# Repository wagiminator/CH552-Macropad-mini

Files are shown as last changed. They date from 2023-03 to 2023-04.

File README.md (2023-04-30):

# CH552E MacroPad mini
The MacroPad mini is a highly versatile keyboard extension that boasts three programmable keys. These keys can be configured to execute a vast array of actions, including the triggering of specific key combinations and sequences. Additionally, the firmware used to operate the MacroPad can be easily modified to suit the needs of the user.

Each button on the MacroPad is also equipped with an addressable LED (NeoPixel), which can be programmed in the same way as the keys. This provides the user with an additional level of customization, allowing them to assign specific colors or patterns to each key, making them easier to identify at a glance.

Connecting the MacroPad to a PC is a breeze, as it simply plugs in via USB. Once connected, the MacroPad is immediately recognized by the PC as an HID multimedia keyboard, meaning that it requires no special drivers to function. This makes the MacroPad an incredibly user-friendly and accessible option for those looking to expand their keyboard capabilities.

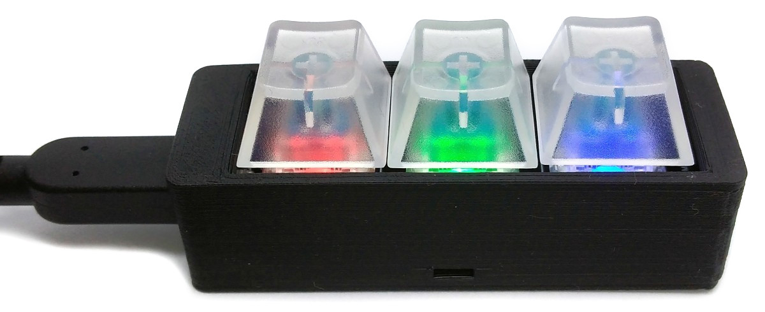
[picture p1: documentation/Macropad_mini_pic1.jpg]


# Hardware
## Schematic
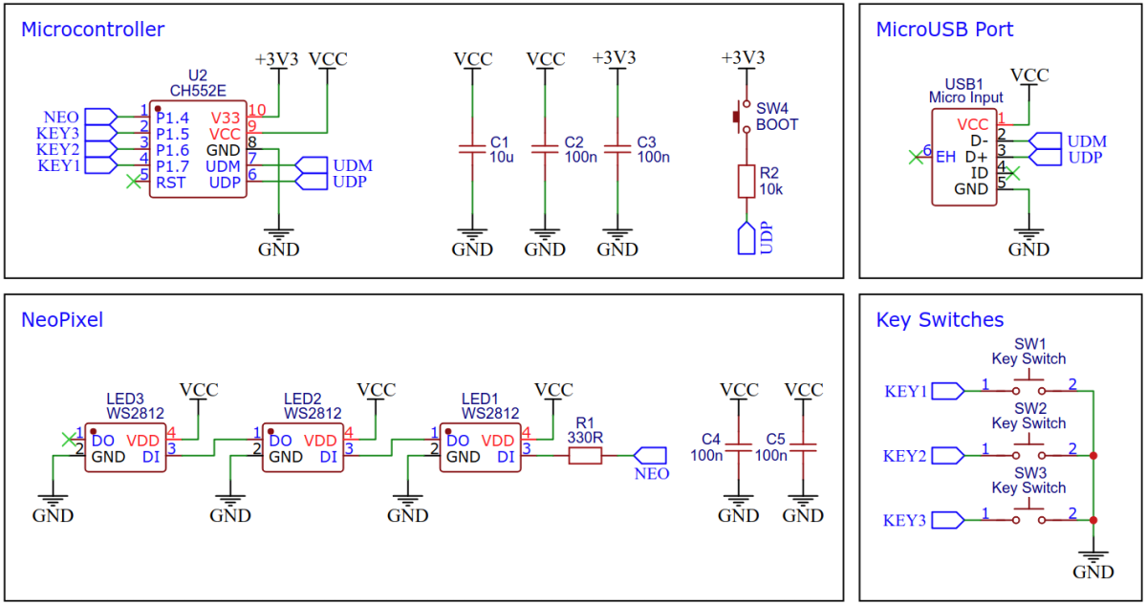
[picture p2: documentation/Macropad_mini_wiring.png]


## CH552E 8-bit USB Device Microcontroller
The CH552E is a low-cost, enhanced E8051 core microcontroller compatible with the MCS51 instruction set. It has an integrated USB 2.0 controller with full-speed data transfer (12 Mbit/s) and supports up to 64 byte data packets with integrated FIFO and direct memory access (DMA). The CH552E has a factory built-in bootloader so firmware can be uploaded directly via USB without the need for an additional programming device.

## Buildung Instructions
1. Take the Gerber files and send them to a PCB manufacturer of your choosing. They will use these files to create the circuit board for your device.
2. Once you have the PCB, you can start soldering the components onto it. Use the BOM (bill of materials) and schematic as a guide to make sure everything is connected correctly.
3. Upload the firmware by following the instructions in the next section (see below).
4. To create the case for your device, use the STL files with your 3D printer. Make sure to use transparent filament for the keycaps.
5. After printing, secure the PCB to the bottom of the case using four self-tapping M2x5mm screws.
6. Finally, assemble the case. Place the keycaps onto the switches. Your device is now ready to use!

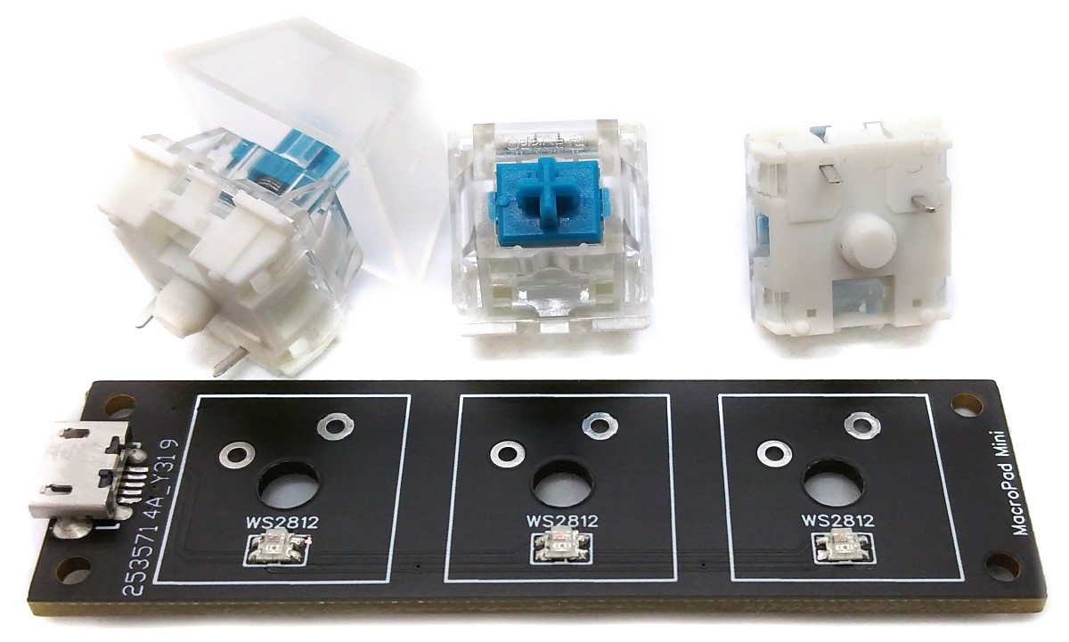
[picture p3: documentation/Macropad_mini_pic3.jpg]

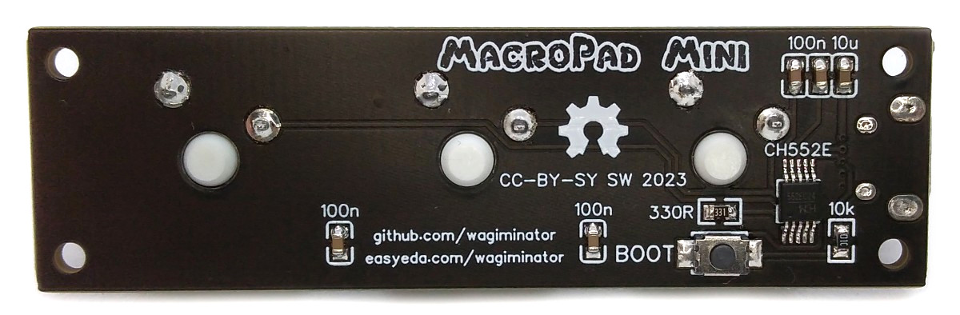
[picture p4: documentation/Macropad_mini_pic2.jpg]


# Modifying, Compiling and Installing Firmware
## Customizing the Firmware
The definition of the macros and their assignment to individual key events is done by adjusting the firmware accordingly, which allows maximum freedom and flexibility. To do this, open the macropad_mini.c file and edit the section with the macro functions. The source code is commented in such a way that it should be possible to make adjustments even with basic programming skills.

## Preparing the CH55x Bootloader
### Installing Drivers for the CH55x Bootloader
On Linux you do not need to install a driver. However, by default Linux will not expose enough permission to upload your code with the USB bootloader. In order to fix this, open a terminal and run the following commands:

```
echo 'SUBSYSTEM=="usb", ATTR{idVendor}=="4348", ATTR{idProduct}=="55e0", MODE="666"' | sudo tee /etc/udev/rules.d/99-ch55x.rules
sudo service udev restart
```

For Windows, you need the [CH372 driver](http://www.wch-ic.com/downloads/CH372DRV_EXE.html). Alternatively, you can also use the [Zadig Tool](https://zadig.akeo.ie/) to install the correct driver. Here, click "Options" and "List All Devices" to select the USB module, and then install the libusb-win32 driver. To do this, the board must be connected and the CH55x must be in bootloader mode.

### Entering CH55x Bootloader Mode
A brand new chip starts automatically in bootloader mode as soon as it is connected to the PC via USB. Once firmware has been uploaded, the bootloader must be started manually for new uploads. To do this, the board must first be disconnected from the USB port and all voltage sources. Now press the BOOT button and keep it pressed while reconnecting the board to the USB port of your PC. The chip now starts again in bootloader mode, the BOOT button can be released and new firmware can be uploaded within the next couple of seconds.

Once the MacroPad firmware is installed, the bootloader can also be entered by holding down key 1 while connecting the device to the USB port. In this way, the case does not have to be opened when new firmware is to be installed. All NeoPixels will then light up white as long as the device is in bootloader mode (approx. 10 seconds).

## Compiling and Uploading using the makefile
### Installing SDCC Toolchain for CH55x
Install the [SDCC Compiler](https://sdcc.sourceforge.net/). In order for the programming tool to work, Python3 must be installed on your system. To do this, follow these [instructions](https://www.pythontutorial.net/getting-started/install-python/). In addition [pyusb](https://github.com/pyusb/pyusb) must be installed. On Linux (Debian-based), all of this can be done with the following commands:

```
sudo apt install build-essential sdcc python3 python3-pip
sudo pip install pyusb
```

### Compiling and Uploading Firmware
- Open a terminal.
- Navigate to the folder with the makefile. 
- Connect the board and make sure the CH55x is in bootloader mode. 
- Run ```make flash``` to compile and upload the firmware. 
- If you don't want to compile the firmware yourself, you can also upload the precompiled binary. To do this, just run ```python3 ./tools/chprog.py macropad_mini.bin```.

## Compiling and Uploading using the Arduino IDE
### Installing the Arduino IDE and CH55xduino
Install the [Arduino IDE](https://www.arduino.cc/en/software) if you haven't already. Install the [CH55xduino](https://github.com/DeqingSun/ch55xduino) package by following the instructions on the website.

### Compiling and Uploading Firmware
- Copy the .ino and .c files as well as the /src folder together into one folder and name it like the .ino file. 
- Open the .ino file in the Arduino IDE.
- Go to **Tools -> Board -> CH55x Boards** and select **CH552 Board**.
- Go to **Tools** and choose the following board options:
  - **Clock Source:**   16 MHz (internal)
  - **Upload Method:**  USB
  - **USB Settings:**   USER CODE /w 266B USB RAM
- Connect the board and make sure the CH55x is in bootloader mode. 
- Click **Upload**.

# References, Links and Notes
1. [EasyEDA Design Files](https://oshwlab.com/wagiminator)
2. [CH551/552 Datasheet](http://www.wch-ic.com/downloads/CH552DS1_PDF.html)
3. [SDCC Compiler](https://sdcc.sourceforge.net/)
4. [CH552G MacroPad plus](https://github.com/wagiminator/CH552-MacroPad-plus)
5. [CH552E USB Knob](https://github.com/wagiminator/CH552-USB-Knob)

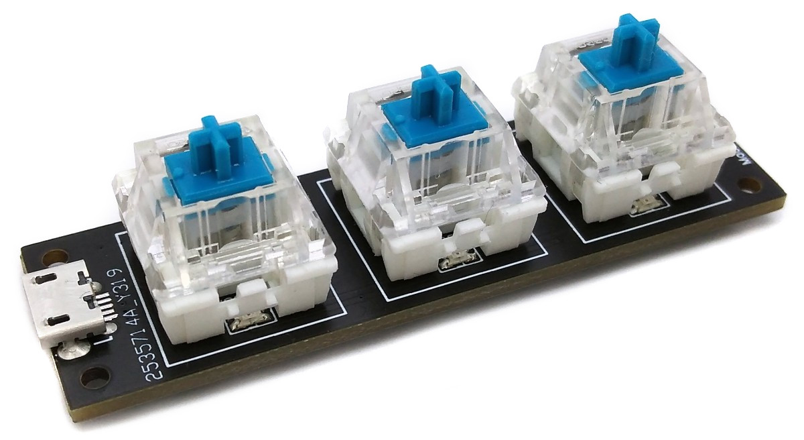
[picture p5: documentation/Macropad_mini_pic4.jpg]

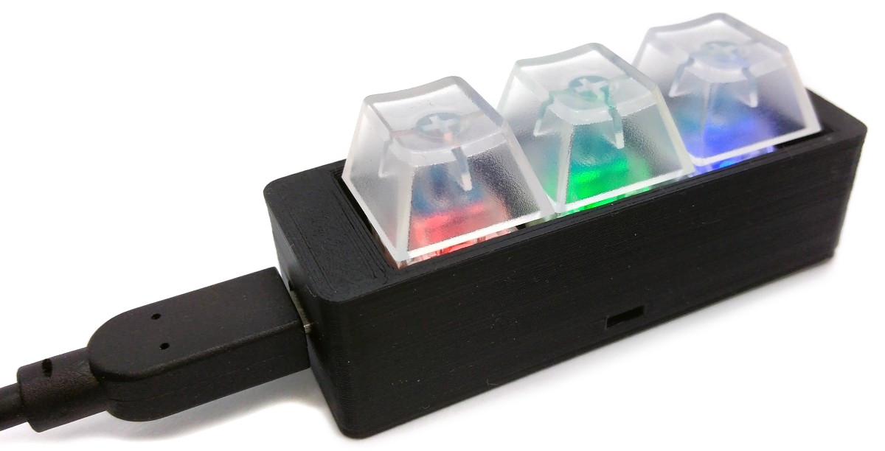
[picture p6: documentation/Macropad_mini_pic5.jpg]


# License


This work is licensed under Creative Commons Attribution-ShareAlike 3.0 Unported License. 
(http://creativecommons.org/licenses/by-sa/3.0/)

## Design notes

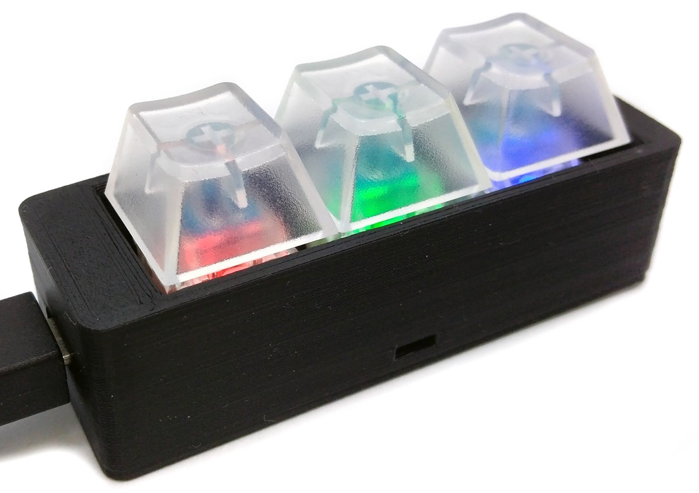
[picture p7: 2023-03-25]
documentation/Macropad_mini_pic6.jpg

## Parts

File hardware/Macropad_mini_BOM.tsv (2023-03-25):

ID | Name | Designator | Footprint | Quantity | Manufacturer Part | Manufacturer | Supplier | Supplier Part
1 | 10u | C1 | C_0603 | 1 | CL10A106KP8NNNC | SAMSUNG | LCSC | C19702
2 | 100n | C2,C3,C4,C5 | C_0603 | 4 | CC0603KRX7R9BB104 | YAGEO | LCSC | C14663
3 | WS2812 | LED1,LED2,LED3 | WS2812-2020 | 3 | WS2812C-2020-V1 | worldsemi | LCSC | C2976072
4 | 330R | R1 | 0603 | 1 | 0603WAF3300T5E | UniOhm | LCSC | C23138
5 | 10k | R2 | 0603 | 1 | 0603WAF1002T5E | UniOhm | LCSC | C25804
6 | Key Switch | SW1,SW2,SW3 | KEY-TH | 3 | CPG151101D213 | Kailh(凯华) | LCSC | C400235
7 | BOOT | SW4 | SW-SMD_L4.0-W2.9-LS5.0 | 1 | TS-1185-C-A-B-B | XKB Enterprise | LCSC | C465999
8 | CH552E | U2 | MSOP-10 | 1 | CH552E | WCH(Jiangsu Qin Heng) | LCSC | C967938
9 | Micro Input | USB1 | MINI-USB-SMD_U254-051T-4BH23-S2B | 1 | U254-051T-4BH23-S2B | XKB Enterprise | LCSC | C319164

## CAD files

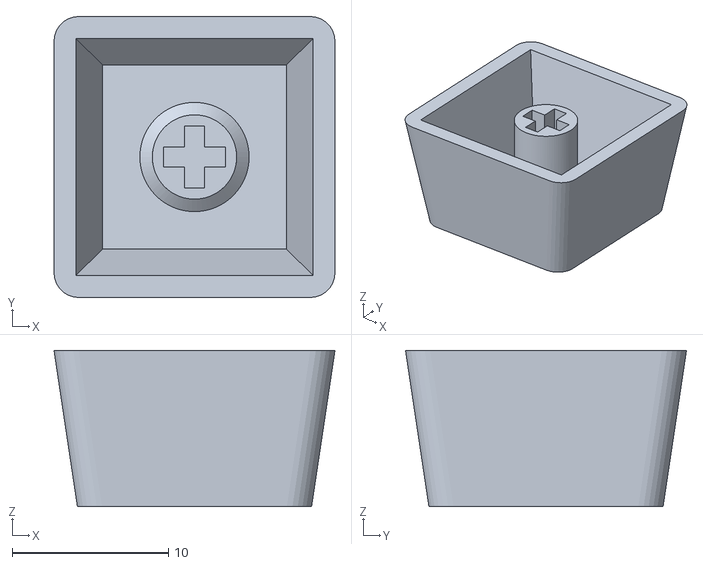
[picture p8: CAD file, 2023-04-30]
3dprint/Macropad_mini_keycap.stl
18.0 x 18.0 x 10.0

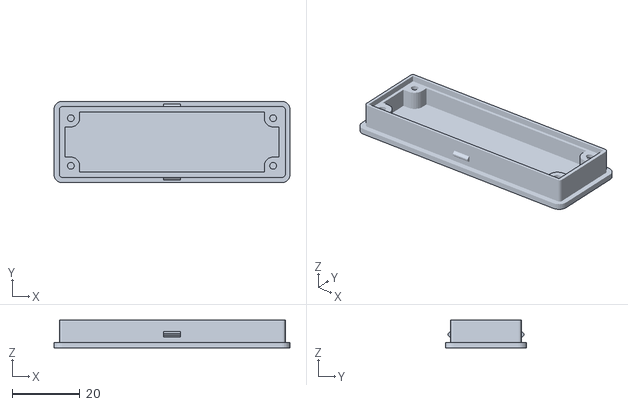
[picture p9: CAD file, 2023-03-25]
3dprint/Macropad_mini_case_bottom.stl
69.8 x 24.1 x 8.20

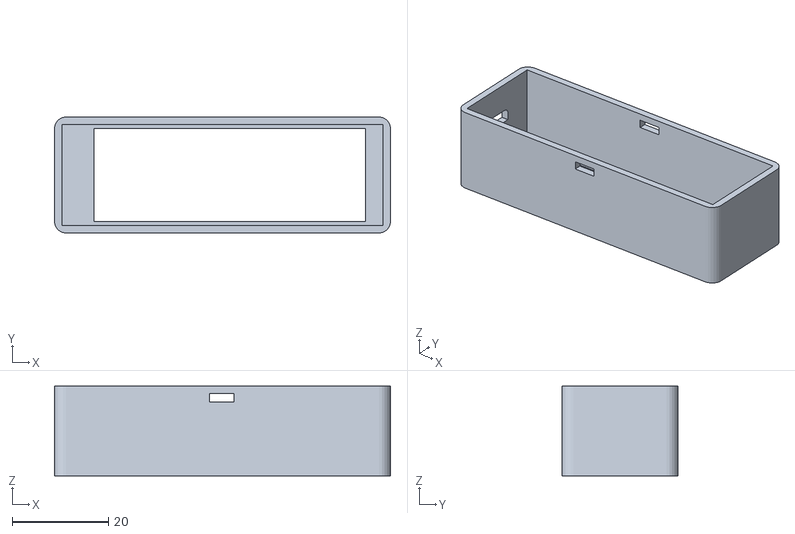
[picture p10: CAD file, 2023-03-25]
3dprint/Macropad_mini_case_top.stl
69.8 x 24.1 x 18.6

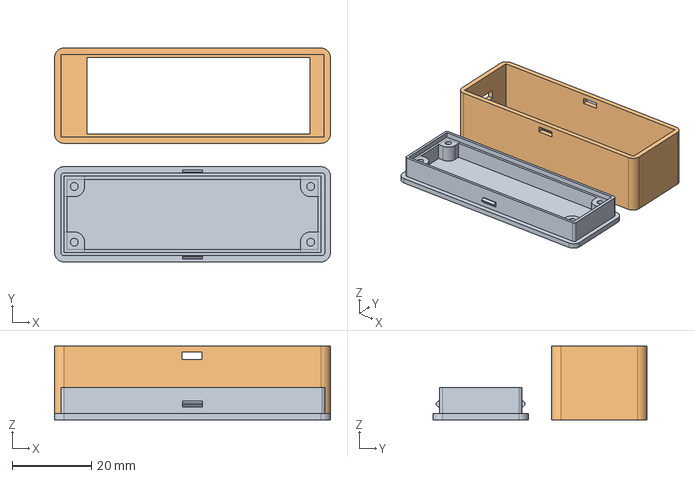
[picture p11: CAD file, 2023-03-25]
3dprint/Macropad_mini_case.fcstd
69.8 x 54.1 x 18.6 mm
Bottom
Top

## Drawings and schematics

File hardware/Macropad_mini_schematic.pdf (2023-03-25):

## MicroUSB Port

## Microcontroller

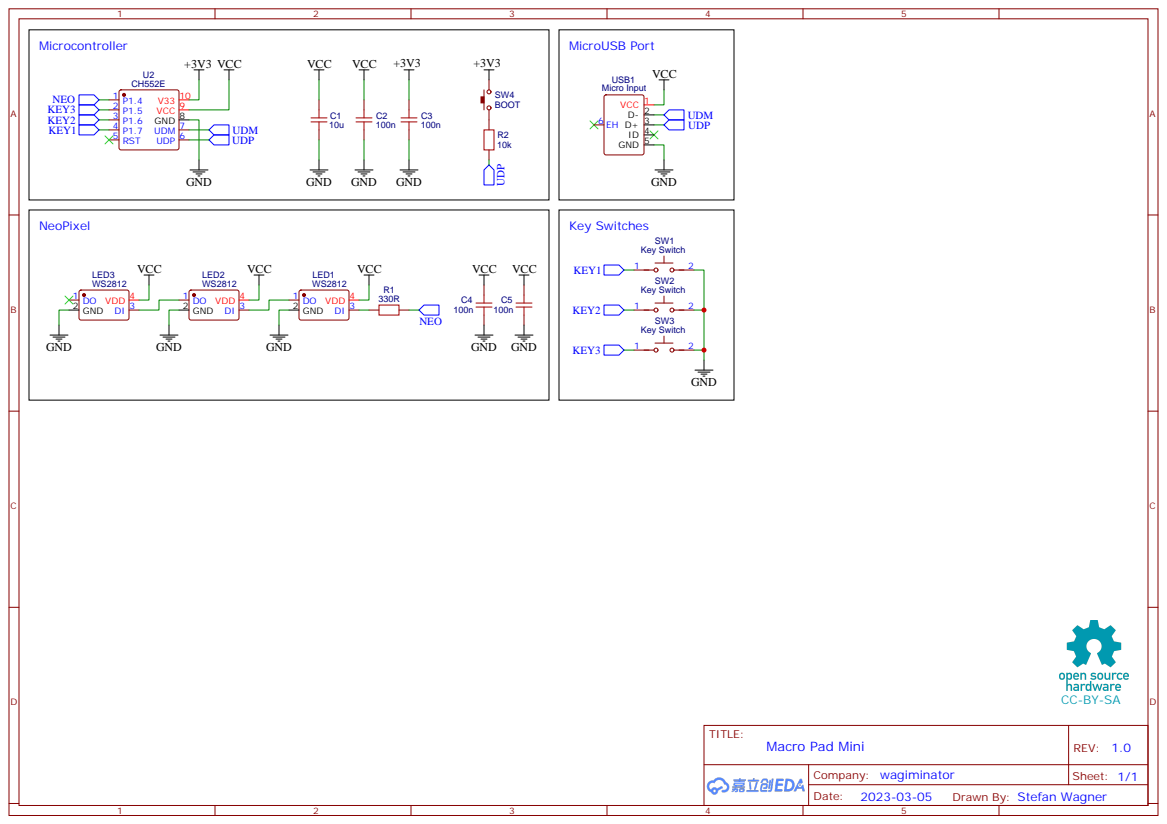
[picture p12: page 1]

Drawn By: Stefan Wagner

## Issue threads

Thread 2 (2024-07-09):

Can't create bin file with arduino

ArthusPVP, 2024-07-09:
Hi, I want to create a bin file to upload to the ch552 but It doesn't works. Can you please give me the versions of the libraries you used for this project 😥? thx

wagiminator, 2024-07-11:
You don't need external libraries, just make sure that the "src" folder is included.

ArthusPVP, 2024-07-11:
Yes, I am able to create the .bin file it it doesn’t work on the macro pad and does some weird things ArthusLe 11 juil. 2024 à 09:03, Stefan Wagner ***@***.***> a écrit :
You don't need external libraries, just make sure that the "src" folder is included.

—Reply to this email directly, view it on GitHub, or unsubscribe.You are receiving this because you authored the thread.Message ID: ***@***.***>

wagiminator, 2024-07-11:
Ah, OK. Did you compile with ArduinoIDE or with the makefile?

ArthusPVP, 2024-07-11:
I compiled with Arduino IDEArthusLe 11 juil. 2024 à 09:34, Stefan Wagner ***@***.***> a écrit :
Ah, OK. Did you compile with ArduinoIDE or with the makefile?

—Reply to this email directly, view it on GitHub, or unsubscribe.You are receiving this because you authored the thread.Message ID: ***@***.***>

wagiminator, 2024-07-11:
Make sure you have the correct settings especially for USB. However, I can't guarantee that this will work with every Arduino version and every version of CH55xduino. The safest way is to compile with make.

ArthusPVP, 2024-07-22:
thx

Closed 2024-07-22.

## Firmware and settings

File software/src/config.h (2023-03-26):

// ===================================================================================
// User Configurations for CH552E USB MacroPad Mini
// ===================================================================================

#pragma once

// Pin definitions
#define PIN_NEO             P14         // pin connected to NeoPixel
#define PIN_KEY3            P15         // pin connected to key 3
#define PIN_KEY2            P16         // pin connected to key 2
#define PIN_KEY1            P17         // pin connected to key 1

// NeoPixel configuration
#define NEO_GRB                         // type of pixel: NEO_GRB or NEO_RGB

// USB device descriptor
#define USB_VENDOR_ID       0x1189      // VID
#define USB_PRODUCT_ID      0x8890      // PID
#define USB_DEVICE_VERSION  0x0100      // v1.0 (BCD-format)

// USB configuration descriptor
#define USB_MAX_POWER_mA    50          // max power in mA 

// USB descriptor strings
#define MANUFACTURER_STR    'w','a','g','i','m','i','n','a','t','o','r'
#define PRODUCT_STR         'M','a','c','r','o','P','a','d'
#define SERIAL_STR          'C','H','5','5','2','x','H','I','D'
#define INTERFACE_STR       'H','I','D','-','K','e','y','b','o','a','r','d'

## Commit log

2023-04-02 Added support for Arduino IDE
2023-04-30 Editorial changes
    [Macropad_mini_keycap.stl]
